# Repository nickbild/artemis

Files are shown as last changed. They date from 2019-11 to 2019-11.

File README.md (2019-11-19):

# Artemis

Artemis is an eyeglass-mounted device that can be configured to locate a specific type of object, or a person.  When the target is found, Artemis will track it with a laser.

<p align="center">

</p>

Higher resolution video in [Media](https://github.com/nickbild/artemis#media) section below.

## How It Works

An eyeglass-mounted camera streams images to a Jetson AGX Xavier.  An SSD300 model is used for object localization within these images.  When the object of interest has been found, a laser diode is turned on.

A servo is also mounted on the eyeglasses for X-axis control of the laser.  A second servo is mounted on top of the first, at a 90 degree angle, to give Y-axis control.  The laser is mounted on the second servo.

Images are thresholded in OpenCV to determine the location of the laser pointer.  With the location of the object, and also the laser, now determined it is possible to adjust the servos to place the laser over the object of interest.

### SSD300 Model

To save time in the prototyping phase, a model pre-trained with the COCO dataset was used ([PyTorch Hub](https://pytorch.org/hub/nvidia_deeplearningexamples_ssd/)).  It is able to recognize and localize [80 different object types](https://github.com/nickbild/artemis/blob/master/category_names.txt).

Any arbitrary model that provides object localization could be inserted in place of this model, and could be trained to detect anything of interest.

### Servo Control

An Adafruit Itsy Bitsy M4 Express microcontroller dev board was used to simplify control of the servos.  The [Arduino sketch is available here](https://github.com/nickbild/artemis/blob/master/servo_handler/servo_handler.ino).

## Media

See it in action.  In this video, Artemis has been directed to find a pair of scissors:  
[YouTube](https://www.youtube.com/watch?v=zOmJOMlqhAQ)

The processing:
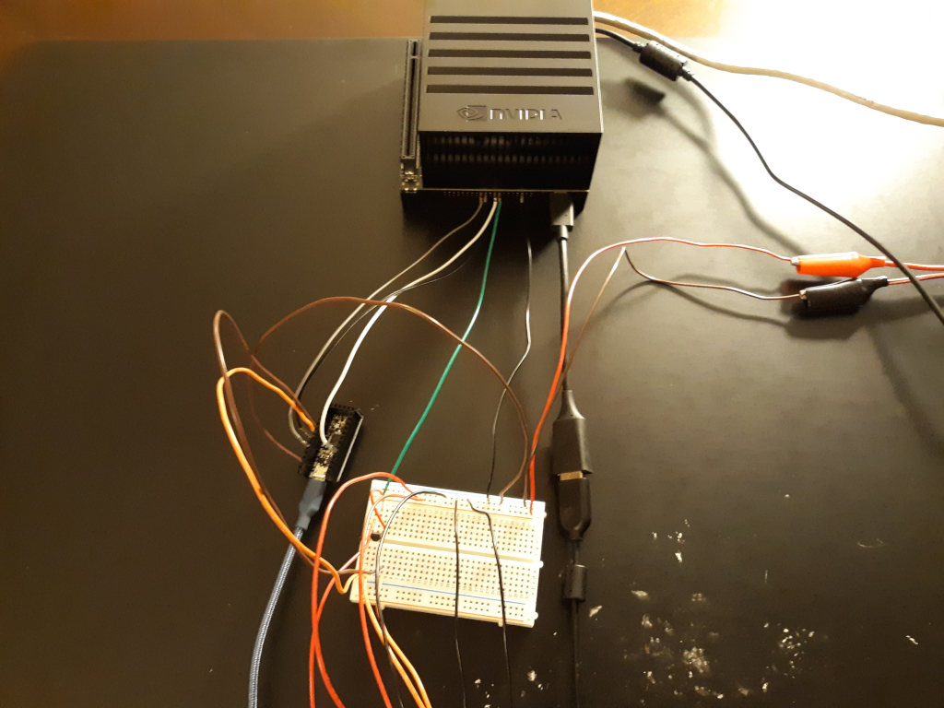
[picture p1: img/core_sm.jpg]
core


The device:
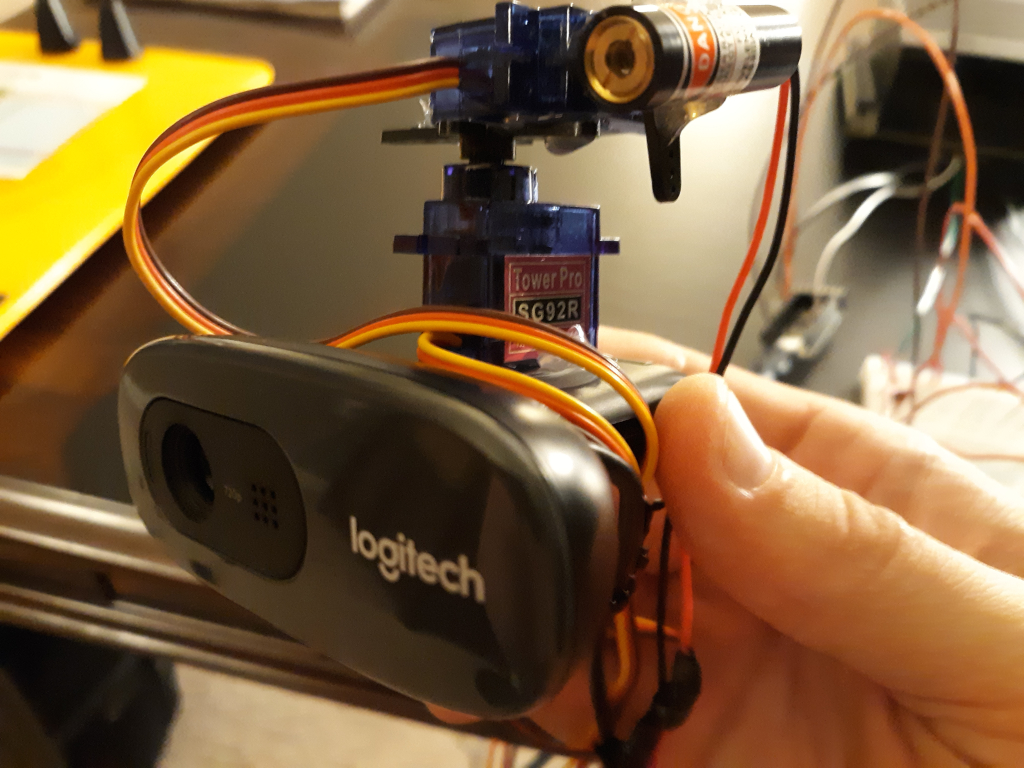
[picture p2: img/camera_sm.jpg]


The glasses:
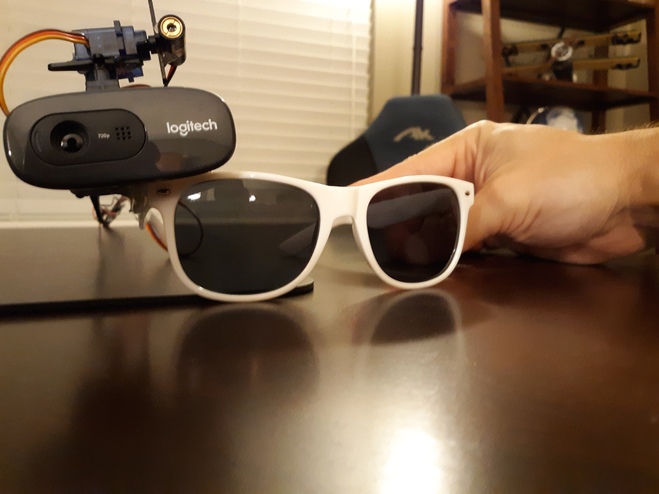
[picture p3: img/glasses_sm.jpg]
glasses


## Software

To run the software, you'll need Python3 with the following modules installed:

```
numpy
cv2
RPi.GPIO
torch
skimage
```

Then clone the repo:

`git clone https://github.com/nickbild/artemis.git`

Switch to the `artemis` directory, then run:

`python3 track_object.py`

## Diagrams

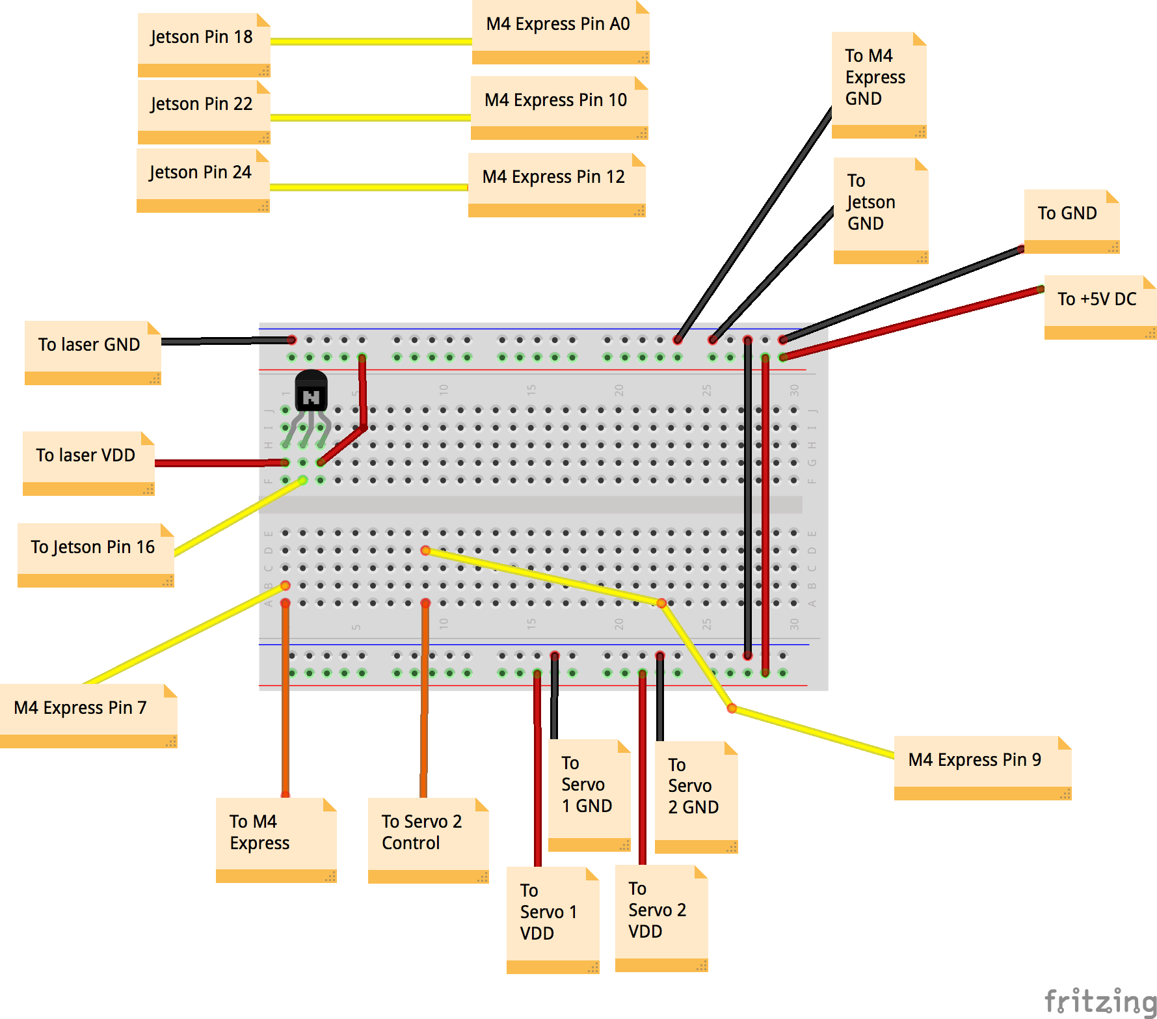
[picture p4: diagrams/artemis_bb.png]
Fritzing Diagram


The Fritzing file can be [downloaded here](https://github.com/nickbild/artemis/raw/master/diagrams/artemis.fzz).

## Bill of Materials

- NVIDIA Jetson AGX Xavier
- Adafruit Itsy Bitsy M4 Express
- USB Webcam
- 2 x micro servos (e.g. Tower Pro SG92R)
- Laser diode
- NPN transistor
- Half breadboard
- Glasses / sunglasses
- Miscellaneous copper wire

## About the Author

[Nick A. Bild, MS](https://nickbild79.firebaseapp.com/#!/)

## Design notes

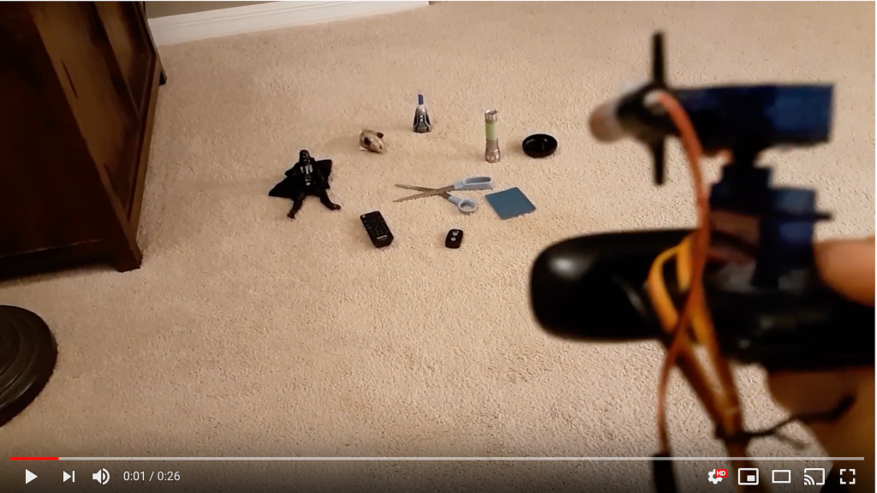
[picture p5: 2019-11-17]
img/youtube_sm.png

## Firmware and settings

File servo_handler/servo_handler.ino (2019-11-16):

#include <Servo.h>

Servo servo1;
Servo servo2;

int pos1 = 90;
int pos2 = 90;

int in1 = 10;
int in2 = 12;
int select_servo = A0;

int in1_active = 1;
int in2_active = 1;

void setup() {
  servo1.attach(9);
  servo2.attach(7);

  pinMode(in1, INPUT);
  pinMode(in2, INPUT);
  pinMode(select_servo, INPUT); // LOW = servo1, HIGH = servo2

  servo1.write(pos1);
  servo2.write(pos2);
}

void loop() {
  ////
  // Modify servo position the first time a high signal is seen on an input.
  ////
  
  if (digitalRead(in1) == HIGH && in1_active) {
    if (digitalRead(select_servo) == LOW) {
      pos1 += 1;
    } else {
      pos2 += 1;
    }
    
    in1_active = 0;
  }
  if (digitalRead(in2) == HIGH && in2_active) {
    if (digitalRead(select_servo) == LOW) {
      pos1 -= 1;
    } else {
      pos2 -= 1;
    }
    
    in2_active = 0;
  }

  ////
  // Adjust servo position.
  ////

  if (pos1 > 180) { pos1 = 180; }
  if (pos2 > 180) { pos2 = 180; }
  if (pos1 < 0) { pos1 = 0; }
  if (pos2 < 0) { pos2 = 0; }

  if (digitalRead(select_servo) == LOW) {
    servo1.write(pos1);
  } else {
    servo2.write(pos2);
  }

  ////
  // When an input goes LOW, reactivate it so it can trigger on the next HIGH signal.
  ////
  
  if (digitalRead(in1) == LOW) {
    in1_active = 1;
  }
  if (digitalRead(in2) == LOW) {
    in2_active = 1;
  }

}

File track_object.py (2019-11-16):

import cv2
import numpy as np
import infer
import servo
import laser_tracker
import laser_control


obj_of_interest = "scissors"          # Object to locate.  COCO class label.
laser_on = False

cap = cv2.VideoCapture(0)
cap.set(3, 1280)
cap.set(4, 720)

# Initialize DL model.
ssd_model, utils, classes_to_labels = infer.init_model()

loop = 0
obj = []
for i in range(15):
    obj.append({'x': None, 'y': None, 'w': None, 'h': None})

while True:
    ret, frame = cap.read()
    frame = cv2.resize(frame, (300, 300))

    # Locate the object of interest in the current frame.
    obj_x, obj_y, obj_w, obj_h = infer.locate_object(frame, obj_of_interest, ssd_model, utils, classes_to_labels)

    
    obj[loop] = {'x': obj_x, 'y': obj_y, 'w': obj_w, 'h': obj_h}

    loop += 1

    if loop == 15:
        loop = 0

    found = False
    found_at = 0
    for i in range(14, -1, -1):
        if obj[i]['x'] is not None:
            found = True
            found_at = i

    # If the object was found...
    if found:
        obj_x = obj[found_at]['x']
        obj_y = obj[found_at]['y']
        obj_w = obj[found_at]['w']
        obj_h = obj[found_at]['h']

        # Turn laser on.
        if not laser_on:
            laser_on = True
            laser_control.on()

        laser_coords = laser_tracker.detect(frame)

        if laser_coords is not None:
            laser_x = laser_coords[0]
            laser_y = laser_coords[1]

            obj_x_center = int(obj_x + (obj_w / 2))
            obj_y_center = int(obj_y + (obj_h / 2))

            #print("Object center at x:{} y:{}".format(obj_x_center, obj_y_center))
            #print("Laser at x:{} y:{}".format(laser_x, laser_y))

            # Move laser point closer to object via servo motion.
            servo.move_laser(obj_x_center, obj_y_center, laser_x, laser_y)
    else:
        # Turn laser off.
        if laser_on:
            laser_on = False
            laser_control.off()

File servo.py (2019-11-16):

import RPi.GPIO as GPIO
from time import sleep


window = 20

dir1 = 25 # Pin 22.
dir2 = 8 # Pin 24.
servo_select = 24 # Pin 18.

GPIO.setmode(GPIO.BCM)
GPIO.setup(dir1, GPIO.OUT, initial=GPIO.LOW)
GPIO.setup(dir2, GPIO.OUT, initial=GPIO.LOW)
GPIO.setup(servo_select, GPIO.OUT, initial=GPIO.LOW)


def move_laser(obj_x, obj_y, x, y):
    if (x + window) < obj_x:
        # Right.
        GPIO.output(servo_select, GPIO.LOW)

        GPIO.output(dir2, GPIO.LOW)
        sleep(0.01)
        GPIO.output(dir2, GPIO.HIGH)
        sleep(0.01)
        GPIO.output(dir2, GPIO.LOW)

    elif (x - window) > obj_x:
        # Left
        GPIO.output(servo_select, GPIO.LOW)

        GPIO.output(dir1, GPIO.LOW)
        sleep(0.01)
        GPIO.output(dir1, GPIO.HIGH)
        sleep(0.01)
        GPIO.output(dir1, GPIO.LOW)

    if (y + window) < obj_y:
        # Down.
        GPIO.output(servo_select, GPIO.HIGH)

        GPIO.output(dir1, GPIO.LOW)
        sleep(0.01)
        GPIO.output(dir1, GPIO.HIGH)
        sleep(0.01)
        GPIO.output(dir1, GPIO.LOW)

    elif (y - window) > obj_y:
        # Up.
        GPIO.output(servo_select, GPIO.HIGH)

        GPIO.output(dir2, GPIO.LOW)
        sleep(0.01)
        GPIO.output(dir2, GPIO.HIGH)
        sleep(0.01)
        GPIO.output(dir2, GPIO.LOW)

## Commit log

2019-11-11 Add improved laser tracker.
2019-11-13 Give some padding on laser adjustments.
2019-11-15 Automatically turn on/off laser.
2019-11-15 Test servo.
2019-11-15 Use microcontroller for servo control.
2019-11-16 Slow servo adjustments.
2019-11-16 Slow laser movements down.
2019-11-17 Add documentation.
    [artemis.fzz]
